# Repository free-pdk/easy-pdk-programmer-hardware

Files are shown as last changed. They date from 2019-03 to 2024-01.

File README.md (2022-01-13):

# easy-pdk-programmer-hardware
Easy PDK programmer for PADAUK microcontroller. EDA, schematic, gerber, bom, housing stl, firmware

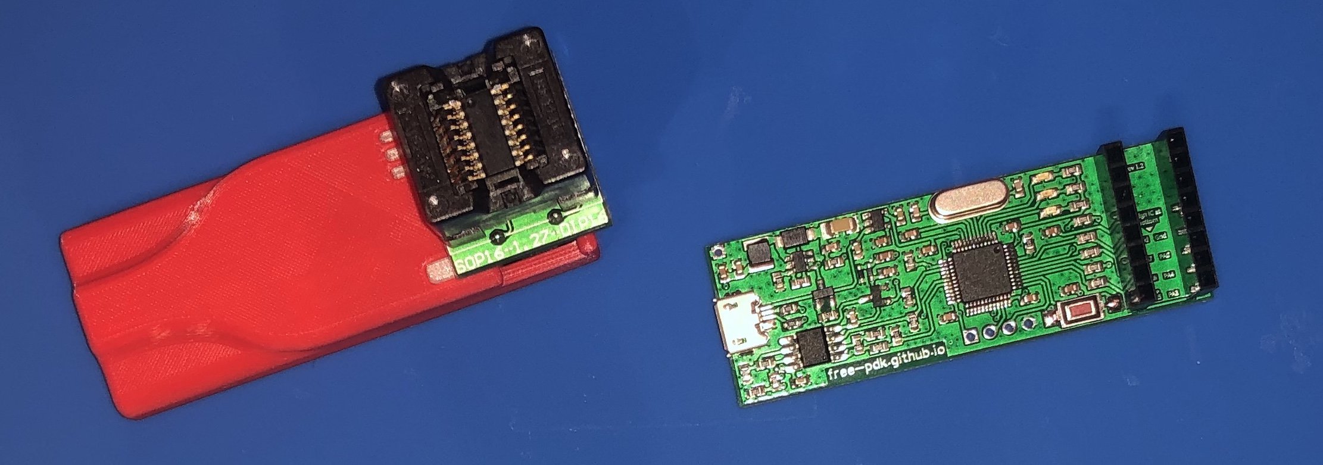
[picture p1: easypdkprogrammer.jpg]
Easy PDK Programmer


Software sources can be found here:  
https://github.com/free-pdk/easy-pdk-programmer-software

PCB gerber files:  
[PCB files](pcb "PCB files")

Easy PCB and components ordering via kitspace.org:  
https://kitspace.org/boards/github.com/free-pdk/easy-pdk-programmer-hardware/

PCB, component placement and assembly pictures:

<a href="https://htmlpreview.github.io/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">==&gt; Click here for interactive component placement bom &lt;==</a>

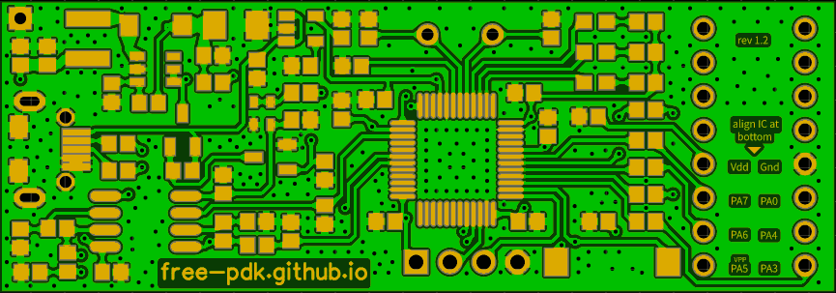
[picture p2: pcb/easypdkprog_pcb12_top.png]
PCB top


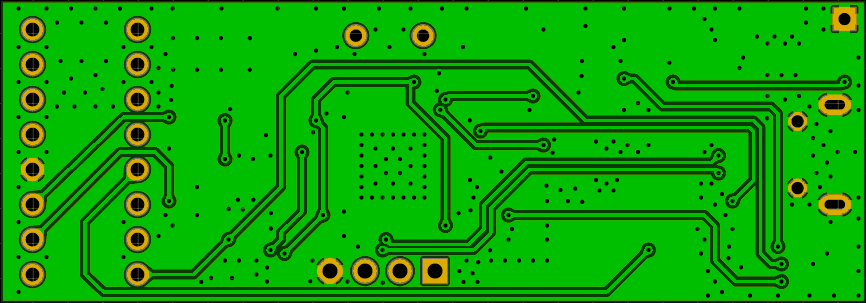
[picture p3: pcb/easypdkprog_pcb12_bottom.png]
PCB bottom


Component placement

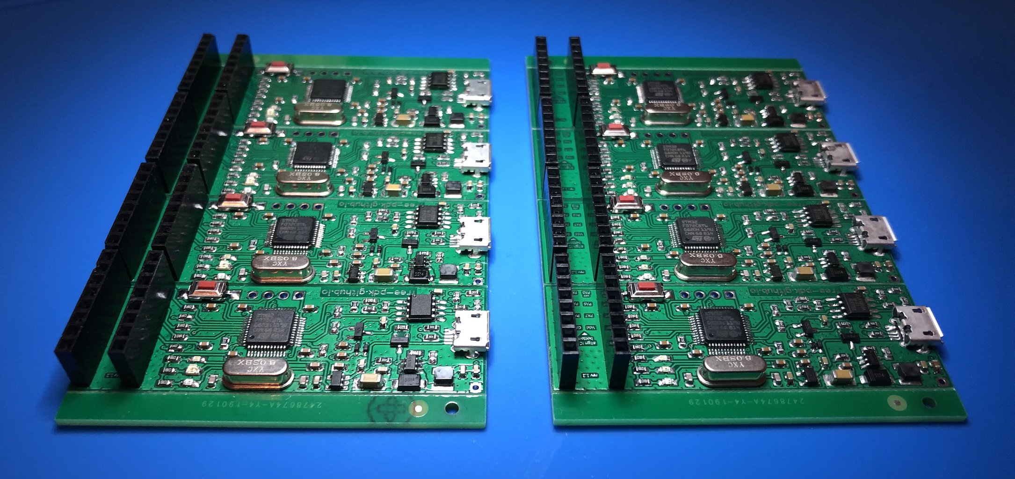
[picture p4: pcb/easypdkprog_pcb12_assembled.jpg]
PCB assembled


After assembling the PCB, you have to install the firmware on the MCU. The firmware can be found in the software repository: https://github.com/free-pdk/easy-pdk-programmer-software/tree/master/Firmware

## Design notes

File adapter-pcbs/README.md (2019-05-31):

# Programming adapter PCBs

This directory contains several adapter pcbs for programming Padauk ICs that
don't have a pinout directly compatible with the easy-pdk-programmer hardware.

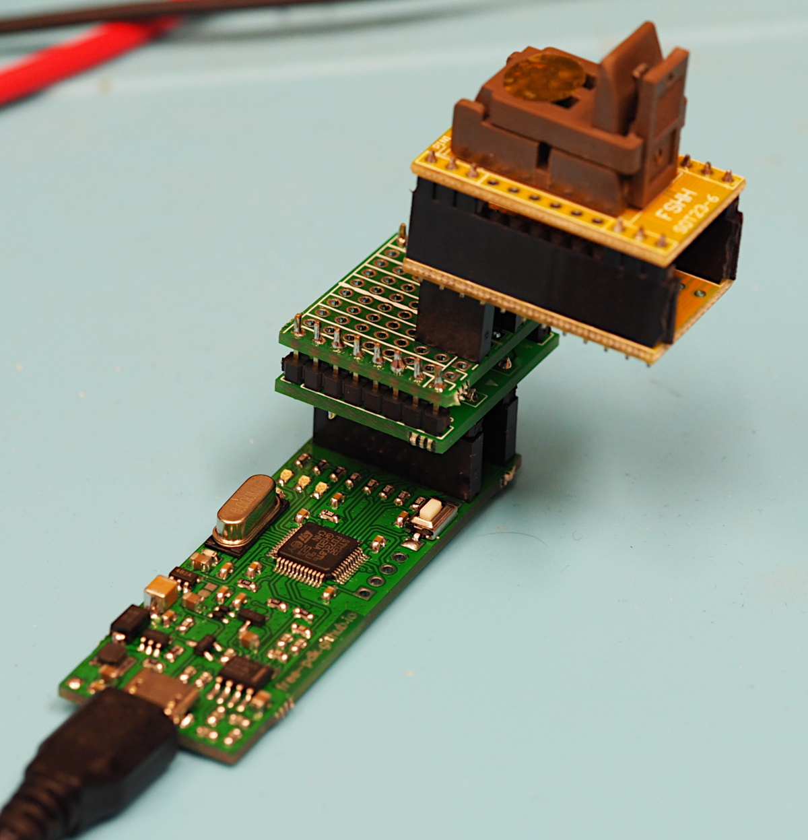
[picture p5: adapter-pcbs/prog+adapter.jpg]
Programmer with adapters


Since most programming sockets available on the market use a pin header spacing
of 0.3" like the programmer itself, one pcb isn't enough for an adapter. So all
adapters are built from 2 pcbs:

  - a bottom pcb, which does the actual routing of the programmer pins to the
    pins needed for the Padauk microcontroller
  - a top pcb, which routes the pins through strait and allows to provide
    socket headers in the necessary spacing for the actual programming socket

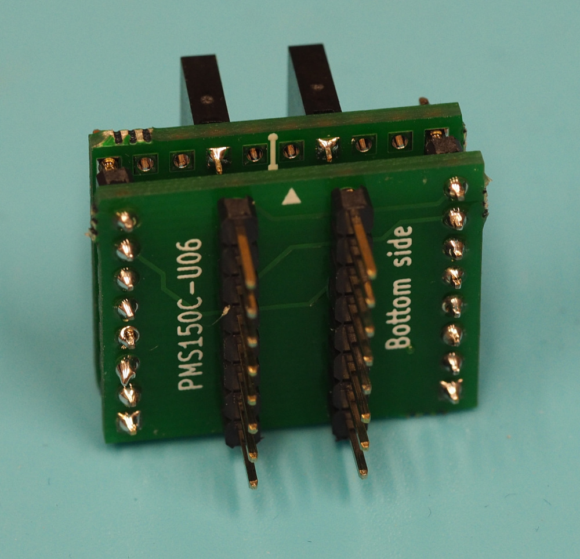
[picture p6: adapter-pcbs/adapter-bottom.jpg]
Bottom pcb of the adapter
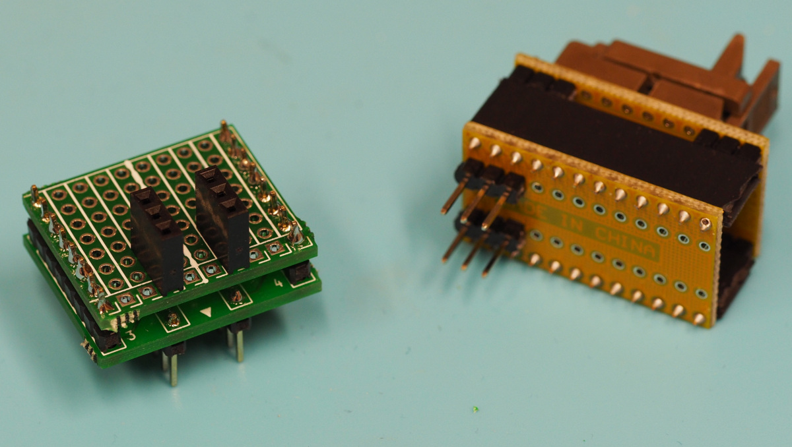
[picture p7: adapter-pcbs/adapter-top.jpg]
Top pcb of the adapter and programming socket
|  |  |

### PMS-Series SOT23-6

This adapter is primarily designed for the PMS150C-U06, but should also work for
other PMS-series ICs in SOT23-6, like the PMS154C-U06 or PMS132B-U06.

### PFS-Series SOT23-6

This adapter is primarily designed for the PFS154-U06, but should also work for
other PFS-series ICs in SOT23-6, like the PFS173-U06.

### SOT23-6 programming socket

The adapter pcbs described above are designed to have a SOT23-6 programming socket plugged into.

I tested this programming socket:
https://www.aliexpress.com/item//32811278237.html
 
### Manual wiring adapter

This is a adapter pcb without connected through tracks between the middle and outer rows.
The white lines in the silkscreen show the breaks. You can solder wires to the holes to
create an adapter for pinouts which don't have their own pcb adapter yet.

### Gerber set

The gerber directory contains a zipped set of Gerber files for a small panel with
all mentioned adapters and the programmer itself.

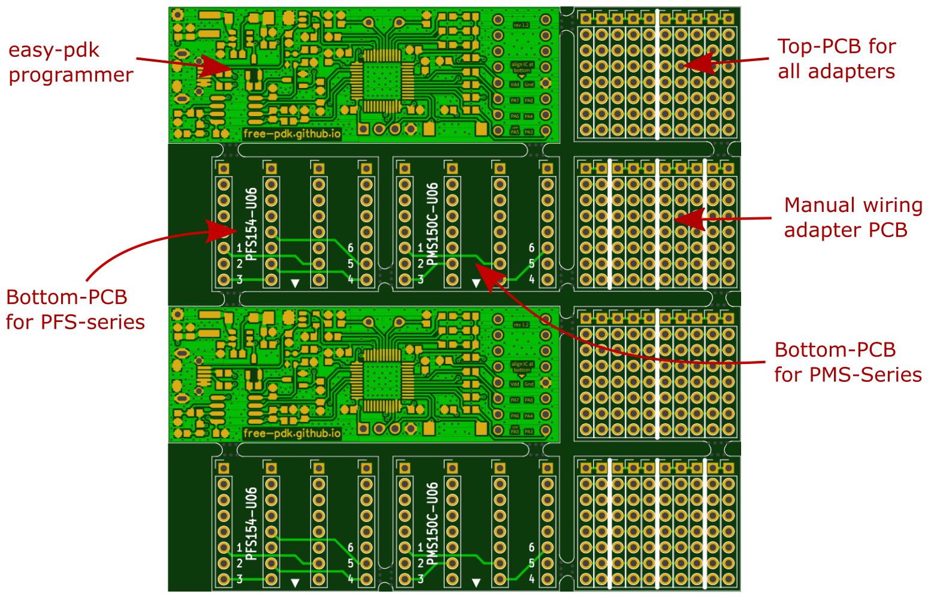
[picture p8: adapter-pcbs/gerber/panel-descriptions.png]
Adapter panel


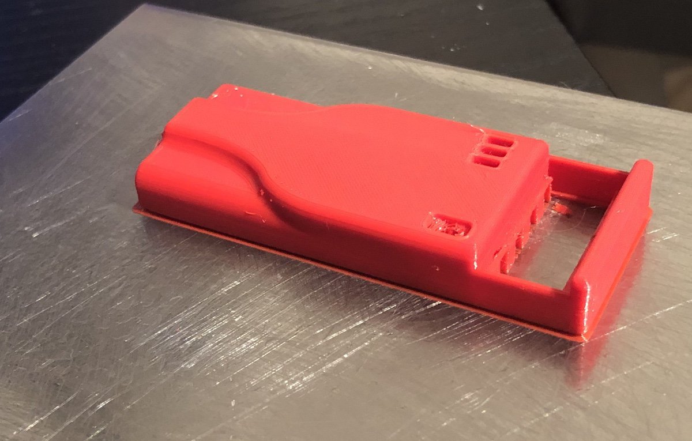
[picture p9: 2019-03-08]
housing/image_housing_top_complete.jpg

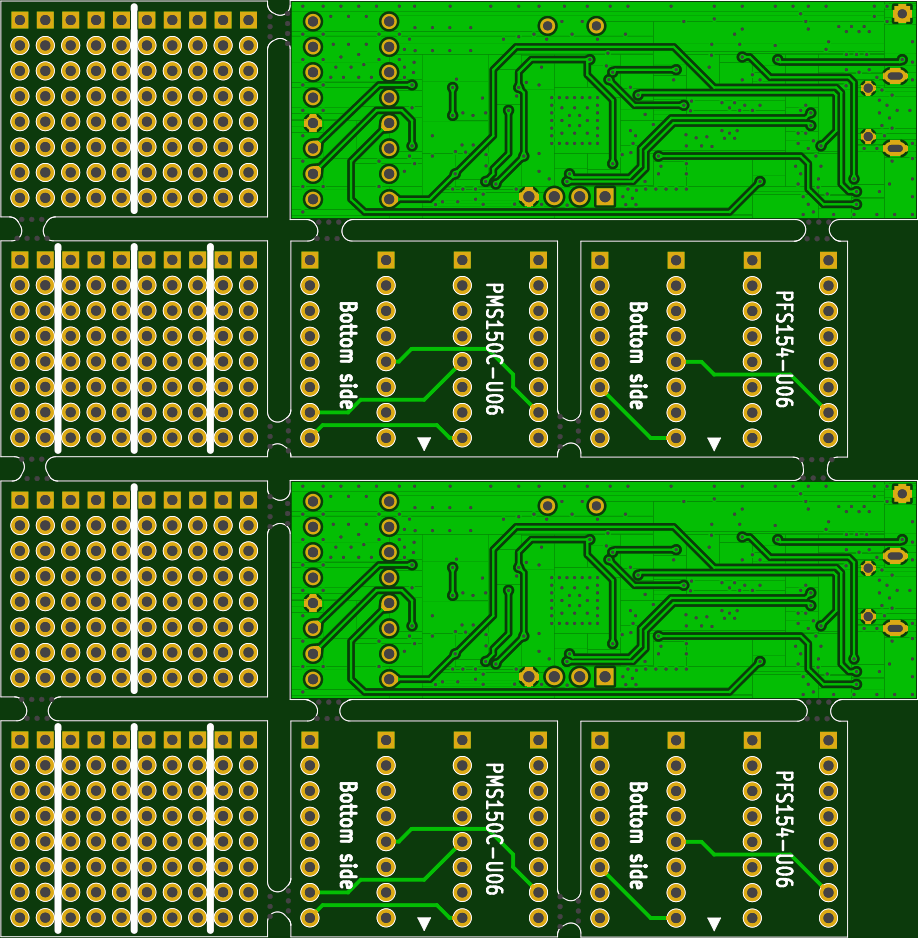
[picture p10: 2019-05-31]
adapter-pcbs/gerber/render-bottom.png

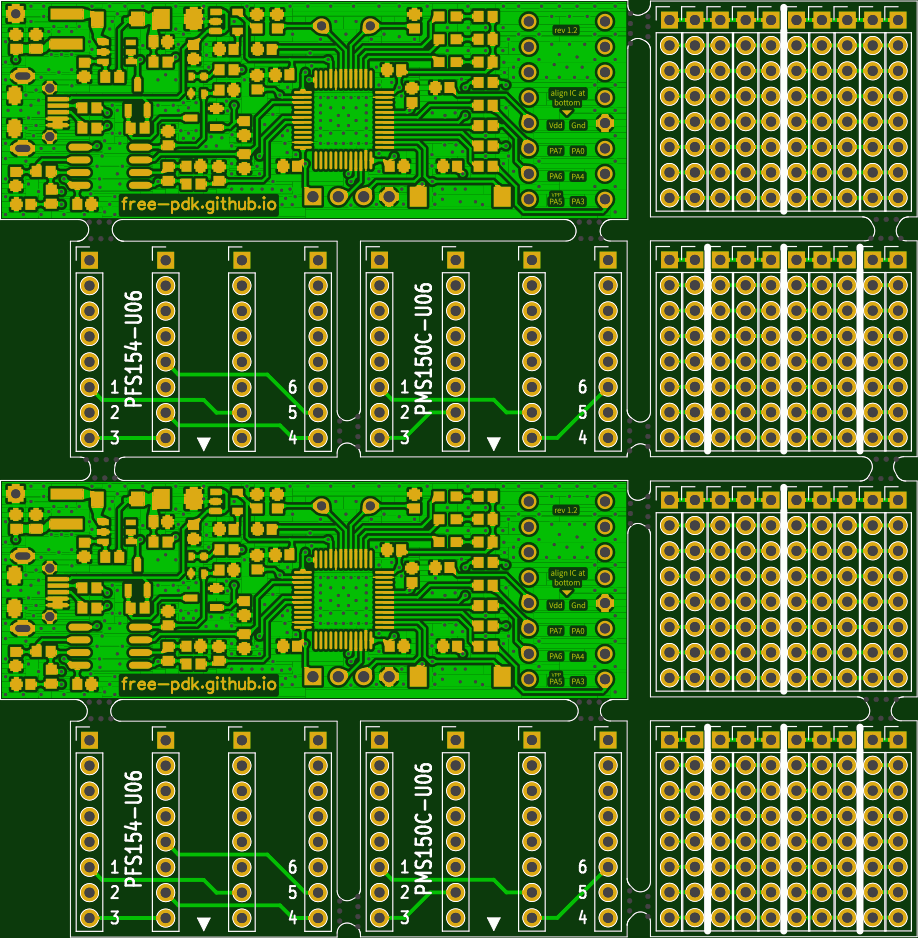
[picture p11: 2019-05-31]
adapter-pcbs/gerber/render-top.png

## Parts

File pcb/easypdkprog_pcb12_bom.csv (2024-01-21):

ID | Name | Designator | Footprint | Quantity | Manufacturer Part | Manufacturer | Supplier | Supplier Part
1 | 47uF | C4 | 1206 | 1 | 1206X476M160NT | FH | LCSC | C172351
2 | IC IN OUT | H1,H2 | 210S-1X8P | 2 | 210S-1*8P L=11.6MMGold-plated black | Ckmtw | LCSC | C27438
3 | STM32F072C8T6 | U1 | LQFP-48_7X7X05P | 1 | STM32F072C8T6 | STMicroelectronics | LCSC | C80488
4 | RT9193-33GB | U2 | SOT-23-5 | 1 | RT9193-33GB | RICHTEK | LCSC | C15651
5 | 4.7uF | C6,C7,C11,C13,C21 | 0603' | 5 | 0603X475K160NT | FH | LCSC | C99229
6 | 20Ω | R10,R11,R24 | 0603' | 3 | RS-03K20R0FT | FH | LCSC | C136605
7 | SWD | SWD | DIP-1X4P-2.54MM-M | 1 | 210S-1*4P L=11.6MMGold-plated black | Ckmtw | LCSC | C124378
8 | 6.8uH | L3 | 3015 | 1 | HPC3015TF-6R8M | TAITEC | LCSC | C155142
9 | FC-DA1608HRK-620D | LED1,LED2,LED3 | LED-0603 | 3 | FC-DA1608HRK-620D | NATIONSTAR | LCSC | C84263
10 | micro USBFemale | USB | MICRO-USB-1 | 1 | micro USBFemale | ValuePro | LCSC | C10418
11 | 100nF | C1,C19,C22,C5,C8,C9,C12,C3,C14,C17,C2,C10 | 0603' | 12 | 0603F104M500NT | FH | LCSC | C42998
12 | 1KΩ | R25,R2,R23 | 0603' | 3 | RC0603FR-071KL | YAGEO | LCSC | C22548
13 | 10K | R1 | 0603' | 1 | RC0603JR-0710KL | YAGEO | LCSC | C99198
14 | 20KΩ | R6,R14,R16,R3,R13,R12 | 0603' | 6 | RS-03K203JT | FH | LCSC | C118368
15 | 240K | R5,R4,R9,R26 | 0603' | 4 | AC0603FR-07240KL | YAGEO | LCSC | C144679
16 | 100K | R17,R15 | 0603' | 2 | RC0603FR-07100KL | YAGEO | LCSC | C14675
17 | 100Ω | R18,R19,R21,R20,R22 | 0603' | 5 | AC0603FR-07100RL | YAGEO | LCSC | C125923
18 | 6.2KΩ | R8,R7 | 0603' | 2 | RC0603JR-076K2L | YAGEO | LCSC | C137614
19 | 8MHz | X1 | HC-49S | 1 | X49SD8MSB2SC | YXC | LCSC | C114147
20 | 20pF | C15,C16 | 0603' | 2 | 0603CG200J500NT | FH | LCSC | C91702
21 | 1TS002E-2700-2500 | SW1 | KEY-TACT-SMD-6.1*3.7*2.5 | 1 | 1TS002E-2700-2500 | HYP | LCSC | C319367
22 | SS14F | D1 | SMAF | 1 | SS14F | SK | LCSC | C110213
23 | GND | P1 | HDR-1X1/2.54 | 1 | Header-Male-2.54_1x1 | ReliaPro | LCSC | C81276
24 | MT3608 | U6 | SOT-23-6 | 1 | MT3608 | AEROSEMI | LCSC | C84817
25 | RB521S-30 | D2,D3 | SOD-523F | 2 | RB521S-30 | SK | LCSC | C122862
26 | BSS84 | Q2 | SOT-23(SOT-23-3) | 1 | BSS84 | SK | LCSC | C112238
27 | BSS138 | Q1 | SOT-23(SOT-23-3) | 1 | BSS138 | SK | LCSC | C112239
28 | AS358AMTR-E1 | U3 | SOIC-8_150MIL | 1 | AS358AMTR-E1 | Diodes Incorporated | LCSC | C141322

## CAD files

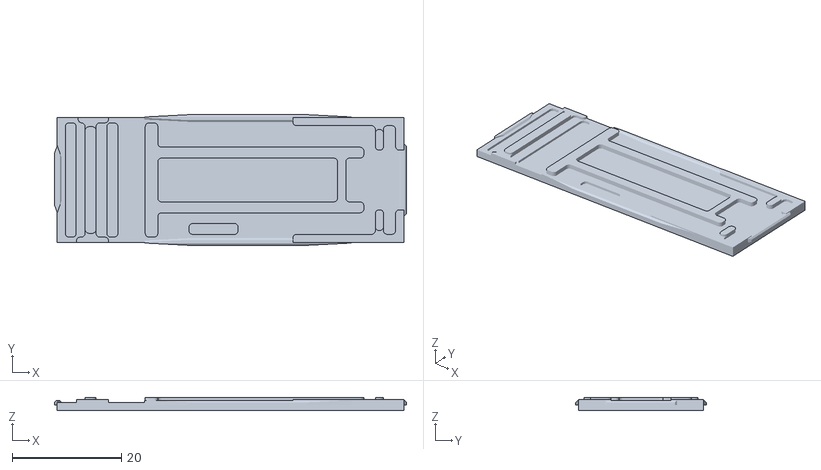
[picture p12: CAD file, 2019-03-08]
housing/easypdkprog_housing_bottom.stl
64.4 x 23.9 x 2.40

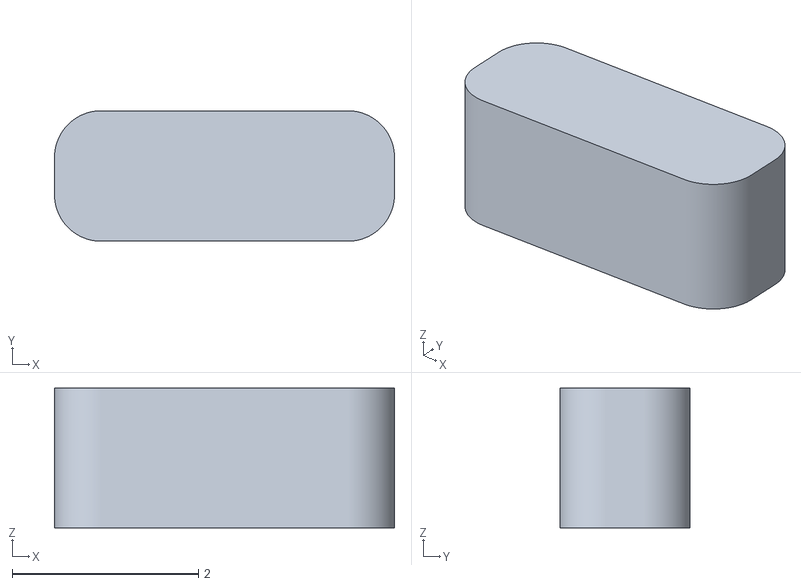
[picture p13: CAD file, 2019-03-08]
housing/easypdkprog_housing_lightguide.stl
3.65 x 1.40 x 1.50

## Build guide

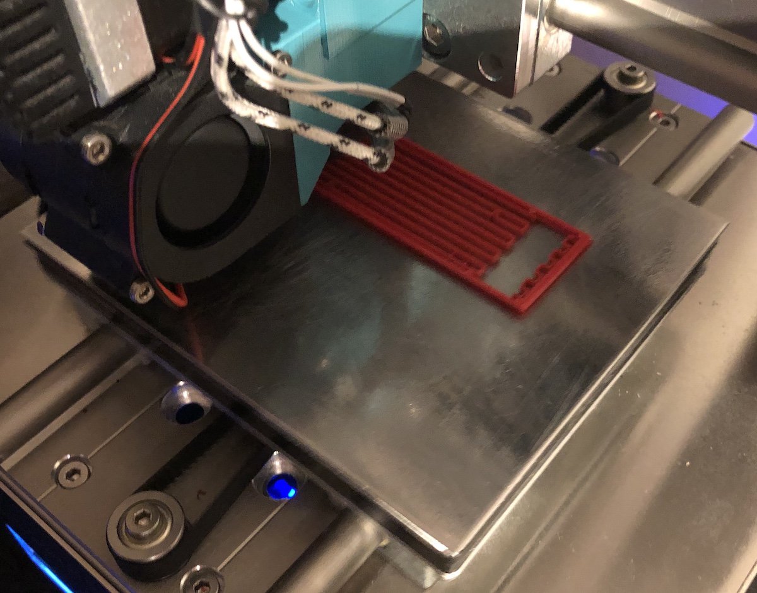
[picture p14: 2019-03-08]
housing/image_printing_housing_top_with_support.jpg

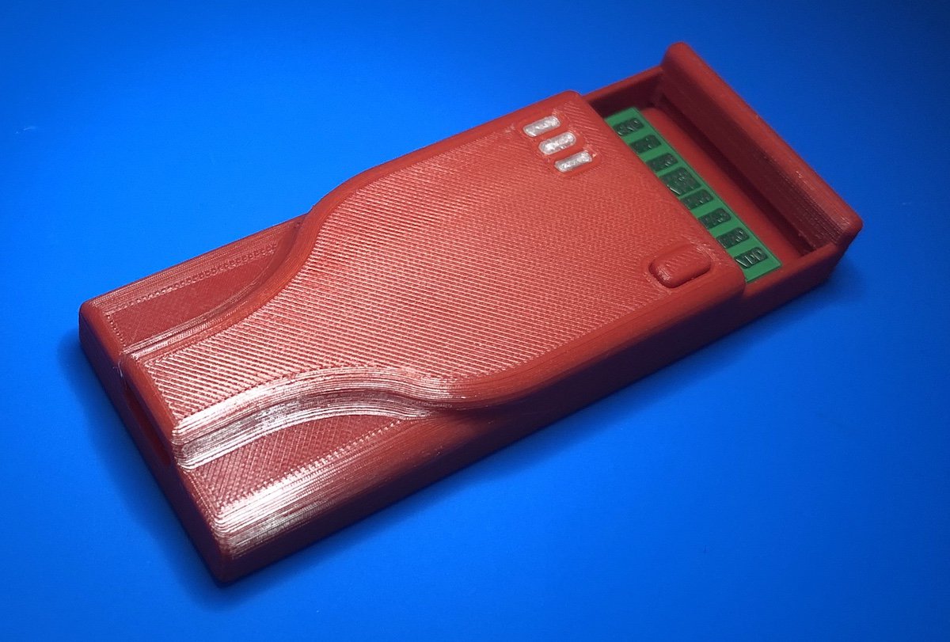
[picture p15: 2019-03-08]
housing/image_housing_assembled.jpg

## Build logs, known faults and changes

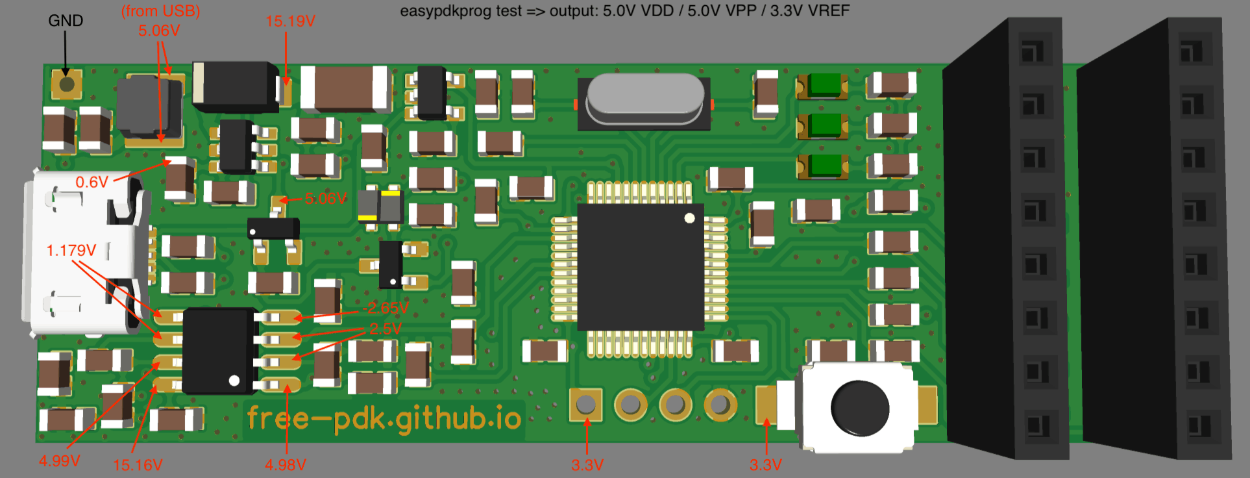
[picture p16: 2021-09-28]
pcb/easypdkprog_pcb12_troubleshooting.png

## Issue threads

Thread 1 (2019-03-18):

Male headers in BOM

electroniceel, 2019-03-18:
The easypdkprog_pcb12_bom.csv has the headers H1 and H2.

The LCSC part listed is C124381. This seems to be a male header.

But all the photos of the pcb show a female header. And I'd also say it makes more sense to use a female header to plug adapters in.

A female header at LCSC would be for example C27438.

freepdk, 2019-03-22:
You are right, they should be **FEMALE** headers.

Something I missed changing when moving to revision 1.2

freepdk, 2019-03-23:
Fixed BOM and easy eda file

Closed 2019-03-23.

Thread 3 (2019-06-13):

Modify the EASYEDA question

themindfactory, 2019-06-13:
I want to modify the SCH and PCB, online I load the SCH and PCB but when you change the SCH it does not change the PCB how do you sync them?? Thanks!

freepdk, 2019-06-18:
This is an EASYEDA specific question. They have a dedicated user forum for this kinf od questions.

As far as I remember: Inside of EASYEDA there is a "Update PCB" button in PCB view. For this to work both SCH and PCB must be in same project.

themindfactory, 2019-06-18:
Thanks, never thought of "other" forum... duh.... nice programmer for Padauk! thanks!

Closed 2019-06-18.

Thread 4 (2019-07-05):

Suggestion: Pin 1 indication on silkscreen

jacobjennings, 2019-07-05:
For components which might be in the wrong orientation, a dot for pin 1 near the correct corner would be helpful. Same for diode direction

freepdk, 2019-07-05:
Hi,

In PCB folder is a file "easypdkprog_pcb12_component_placement.pdf" which has the dots like you asking for.

On such small boards it is not feasible to include silk screen, but with the document from above it is relatively easy to assemble.

Closed 2019-08-15.

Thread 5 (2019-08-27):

[Question] Support for PMC232 PMC234 PGC433 PGC434?

DanielMazurkiewicz, 2019-08-27:
Do you plan by any chance do add support in programmer for these microcontrollers?

PMC232
PMC234
PGC433
PGC434

spth, 2019-08-29:
The PMC232,  was officially released 3 days ago (I don't know about actual availability). The PGC433 and PGC434 are still considered "under development". The PMC234 datasheet was released 4 days ago.
While support for these will be very useful, I guess it will take some time.

freepdk, 2019-08-30:
Support can be added only, if a real physical device is available. It is not possible to add support for data sheet only CPUs.

I do have PMC232 and PMC234. Do you have a project and want to use them? If so I will put them on top of the priority list for device support.

DanielMazurkiewicz, 2019-09-01:
>  If so I will put them on top of the priority list for device support.

@freepdk Thank you, that is a very kind of you, but no rush with that. Would like to at some point drive brushed DC motors and having these industrial grade microcontrollers (PFC and PMC series) supported will probably be a must for such a projects. And after couple of days of research among different brands my priority wish list (based on price and capabilities I will need) would look more like that:

1. PMC156 - SOP16
2. PMC150 - SOP8
3. PMC251 - SOP14

Analyzed that in some cases it will be easier to program and cheaper to have two or even three of above plus some external comparator (if necessary) than having one uC that provide all functions on board.

freepdk, 2019-09-02:
@DanielMazurkiewicz

PMx150C is well supported already
PMx156 I can add next
PMC251 is partially supported already (probe/read works, write I need to finish)

DanielMazurkiewicz, 2019-09-02:
Used that file:
https://github.com/free-pdk/easy-pdk-programmer-software/blob/master/fpdkicdata.c
as reference for table below:

| Microcontroller        | Programmer support | SDCC support |
|:----------------------:|:------------------:|:------------:|
|      PFS154            |         ✓          |              |
|      PFS172            |                    |              |
|      PFS173            |         ✓          |              |
|      PMS130            |                    |              |
|      PMS131            |                    |              |
|      PMS132B           |                    |              |
|      PMS133            |                    |              |
|      PMS134            |                    |              |
|      PMS150            |                    |              |
|      PMS150C           |         ✓          |              |
|      PMS150G           |                    |              |
|      PMS152            |                    |              |
|      PMS153            |                    |              |
|      PMS154B           |         ✓          |              |
|      PMS154C           |         ✓          |              |
|      PMS156            |                    |              |
|      PMS171B           |                    |              |
|      PMS232            |                    |              |
|      PMS234            |                    |              |
|      PMS271            |                    |              |
|      PFC151            |                    |              |
|      PFC154            |                    |              |
|      PFC232            |                    |              |
|      PFC433            |                    |              |
|      PFC434            |                    |              |
|      PMC131            |                    |              |
|      PMC150            |         ✓          |              |
|      PMC153            |                    |              |
|      PMC156            |                    |              |
|      PMC232            |                    |              |
|      PMC234            |                    |              |
|      PMC251            |     partial        |              |
|      PMC271            |                    |              |

Feel free to do whatever you want with that table (would be nice to have it somewhere in readme). Here is a markdown for it:
```
| Microcontroller        | Programmer support | SDCC support |
|:----------------------:|:------------------:|:------------:|
|      PFS154            |         ✓          |              |
|      PFS172            |                    |              |
|      PFS173            |         ✓          |              |
|      PMS130            |                    |              |
|      PMS131            |                    |              |
|      PMS132B           |                    |              |
|      PMS133            |                    |              |
|      PMS134            |                    |              |
|      PMS150            |                    |              |
|      PMS150C           |         ✓          |              |
|      PMS150G           |                    |              |
|      PMS152            |                    |              |
|      PMS153            |                    |              |
|      PMS154B           |         ✓          |              |
|      PMS154C           |         ✓          |              |
|      PMS156            |                    |              |
|      PMS171B           |                    |              |
|      PMS232            |                    |              |
|      PMS234            |                    |              |
|      PMS271            |                    |              |
|      PFC151            |                    |              |
|      PFC154            |                    |              |
|      PFC232            |                    |              |
|      PFC433            |                    |              |
|      PFC434            |                    |              |
|      PMC131            |                    |              |
|      PMC150            |         ✓          |              |
|      PMC153            |                    |              |
|      PMC156            |                    |              |
|      PMC232            |                    |              |
|      PMC234            |                    |              |
|      PMC251            |     partial        |              |
|      PMC271            |                    |              |

```

freepdk, 2019-09-02:
Hi,

in development branch are far more supported ICs (most of them Probe/Read only for now).

"easypdkprog list" shows all supported ICs:

$ ./easypdkprog list
Supported ICs:
 PMC251   (0x058): OTP  : 1024 (16 bit), RAM:  96 bytes
 PMS132   (0x109): OTP  : 2048 (14 bit), RAM: 128 bytes
 PMS132B  (0x109): OTP  : 2048 (14 bit), RAM: 128 bytes
 PMS150C  (0xA16): OTP  : 1024 (13 bit), RAM:  64 bytes
 PMS152   (0xA27): OTP  : 1280 (14 bit), RAM:  80 bytes
 PMS271   (0xA58): OTP  : 1024 (16 bit), RAM:  64 bytes
 PFS154   (0xAA1): FLASH: 2048 (14 bit), RAM: 128 bytes
 PMS133   (0xC19): OTP  : 4096 (15 bit), RAM: 256 bytes
 PMS134   (0xC19): OTP  : 4096 (15 bit), RAM: 256 bytes
 PMS131   (0xC83): OTP  : 1536 (14 bit), RAM:  88 bytes
 PMS171B  (0xD36): OTP  : 1536 (14 bit), RAM:  96 bytes
 PMS154B  (0xE06): OTP  : 2048 (14 bit), RAM: 128 bytes
 PMS154C  (0xE06): OTP  : 2048 (14 bit), RAM: 128 bytes
 PFS173   (0xEA2): FLASH: 3072 (15 bit), RAM: 256 bytes

As soon as Write support is added and tested I want to merge this to master version and make a real release.

spth, 2019-09-03:
SDCC, while not including headers yet, can compile programs for them all, except the PMC251 and PMS271.

Philipp

DanielMazurkiewicz, 2019-09-03:
> "easypdkprog list" shows all supported ICs
@freepdk it requires installing easypdkprog to get to know what is supported and what not, so I still think it would be nice to have it in a documentation

freepdk, 2020-07-17:
The website https://free-pdk.github.io/ is now having a list of truly supported ICs.

Closed 2020-07-17.

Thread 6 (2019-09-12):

Help Resolving Occasional Board Issue (“wrong icid”)

paulreimer, 2019-09-12:
After assembling several boards (over 50% working perfectly!) I have an issue with the other 40%, and I haven’t been able to fix it (by metering signals, reworking some parts, etc).

Specifically, while the USB->STM32 works and the programmer is detected, I get “wrong icid” when trying to flash a PFS173.

Can you suggest what parts/traces to check that might cause this? (shorts, unconnected pins, diodes in the wrong orientation, etc)? It would be great to get those boards working and/or understand the likely causes for future builds.

freepdk, 2019-09-15:
Have you tried the latest version of the programmer software on github (easypdkprog v1.1)?

I changed the voltages in "fpdkicdata.c" for PFS173 a bit (especially WRITE CMD voltage) which improves the situation a bit.

-

To debug the hardware there is an extra program called "easypdkprogtest".

Compile it with "make easypdkprogtest" and the execute it (with no IC attached).

It outputs 5V on VPP and VDD and uses internal ADC to measure it.

When you execute it write down the measurements reported from easypdkprogtest and also measure VDD and VPP with a multimeter.

Expectation: All values should be very close to 5V.
If not you should check that after the 2 diodes you get -2.4V when easypdkprogtest is running (check schematics and measure with multimeter). This is the negative reference for the opamp. In case the diodes are wrong / damaged / not soldered properly you get a wrong negative reference voltage which would explain wrong / shifted output voltages for VDD / VCC which could cause the problem you describe.

paulreimer, 2019-09-15:
Thanks for your help with debugging this! Super helpful to have the `easypdkprogtest` and happily I do have several boards that are working well to compare against.

- I updated all my boards to 1.1 F/W, the working boards still work and the "wrong ICID" boards still report the same.
- I ran `easypdkprogtest` and the working boards have ~5V for both VDD and VPP. The bad boards have ~13.66V for VDD and ~5V for VPP (multimeter confirms this at the IC pins).
- I checked the voltage w.r.t. GND for diodes D2 + D3, and they appear to be similar for both the good boards and the bad boards (-2.7v D3<->GND, and 0.0v D2<->GND, -1.5v<->GND for both diodes on the shared side). I'm not sure where to probe to find 2.4v.

So now I'm wondering about the opamp (maybe that needs to be replaced?), and also about the xtal as you suggest (but continuity test seems good.) If you have any other pointers, please let me know! I'm already feeling a lot better knowing that I can confirm some of the symptoms with `easypdkprogtest`.

freepdk, 2019-09-16:
Hi,
>     * I ran `easypdkprogtest` and the working boards have ~5V for both VDD and VPP. The bad boards have ~13.66V for VDD and ~5V for VPP (multimeter confirms this at the IC pins).
This explains everything.

Just to be sure. You measure +13V on VDD and +5V on VPP ? This scenario is almost impossible and could be caused by wrong resistor values on the DAC lines only.

>     * I checked the voltage w.r.t. GND for diodes D2 + D3, and they appear to be similar for both the good boards and the bad boards (-2.7v D3<->GND, and 0.0v D2<->GND, -1.5v<->GND for both diodes on the shared side). I'm not sure where to probe to find 2.4v.
I said -2.4V, you measured -2.7V which is ok as negative reference for the opamp (anything less than -2V is fine).

> So now I'm wondering about the opamp (maybe that needs to be replaced?), and also about the xtal as you suggest (but continuity test seems good.)
The XTAL + decoupling caps just need visual inspection of soldering. If you say they are good then they are good. (The 13V problem has nothing to do with XTAL).

* check that there are no solder blobs on MCU pins shorting the DAC outputs to 3V (MCU pin 14, pin 15)
* check resistor values on the dac outputs: **R4**, **R6**, R8, R9 (most likely something wrong with one of these)

freepdk, 2019-09-22:
@paulreimer
Could you solve your problem?

paulreimer, 2019-09-22:
Thanks for checking @freepdk!

I checked the resistor values and they all seem to be correct, the value varies somewhat maybe due to low-ish tolerance, but it doesn’t seem like any values were swapped or shorted. I’m not sure what else to check, but I might order extra parts from LCSC and try to replace the STM32 or op-amp and see if that helps?

Feel free to close this issue if there’s nothing else to check (maybe I cooked the boards a bit too much). I can post something if I learn more about this issue.

freepdk, 2019-09-22:
@paulreimer
Better to find the cause so others can participate from it. I have something like a "troubleshooting" document in mind.

Here a first start:

```
Reference voltages when running easypdkprogtest:

                   +-------+
                   |   O   |
(DAC-VPP) 1.18V -> |5  P  4| <- -2.7V
          1.18V -> |6  A  3| <-  2.49V (DAC-VDD)
(VPP)      5.0V <- |7  M  2| <-  2.49V
          14.9V -> |8  P  1| ->  5.0V  (VDD)
                   |      .|
                   +-------+
```

Please measure the voltages on your non working boards and report back.

Closed 2020-07-17.

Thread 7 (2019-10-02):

VPP/VDD voltage capped to 3.45V

cirlam, 2019-10-02:
Hi,

Firstly, thank you for all the hardwork developing this programmer!

I have a similar (ish) problem to [https://github.com/free-pdk/easy-pdk-programmer-hardware/issues/6](https://github.com/free-pdk/easy-pdk-programmer-hardware/issues/6)  with a hand soldered pcb.

When using easypdkprog probe, It responds with no MCU found (PFS-154C in the socket).

Using easypdkprogtest, it only gets to 3.46v for vdd and 3.44v for vpp. I've confirmed these values with a multimeter. Voltage around the diodes is identical to Paul - (-2.7v D3<->GND, and 0.0v D2<->GND, -1.5v<->GND for both diodes on the shared side).

If I change easypdkprogtest to request 1v or 2v it works perfectly, however it cannot go any higher than this. If I change easypdkprogtest to 100.0, it remains at 3.46v/3.44v.

Visual check of the PCB with microscope looks OK from what I can see.

Any ideas of what I should be checking to resolve this? Thank you!

freepdk, 2019-10-04:
Hi,

this sounds like the dc dc is not generating the 14V. Look at the coil / big diode / the DC DC ic and measure voltages there (when easypdkprogtest is running).

==> check U6  when easypdkprogtest is running:
pin 4/5: input voltage (should be 5V, if is not 5V check the 2 transistors Q1 and Q2)
pin 1: output of high voltage going to big diode (should be around 14V)
pin 3: input of feedback voltage (should be something >5V, sorry can't measure right now)

My guess: big diode is soldered backwards or Q1/Q2 is mixed up.

cirlamOB, 2019-10-04:
Thank you for the help! I will check these this evening and get back to you.

cirlam, 2019-10-04:
Thank you for the help!

I will check these this evening and get back to you.

cirlam, 2019-10-05:
Success! I mistakenly soldered a 100k resistor to R1. Now works fine and detects IC's ok.

freepdk, 2019-10-05:
Great to hear.

Wrong R1 / R5 values will cause a wrong feedback to the DC DC so the output voltage will be incorrect.

Thanks for the feedback.

Closed 2019-10-05.

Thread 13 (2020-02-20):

Documentation: User Manual

Zitt, 2020-02-20:
Is there a user manual somewhere?
Specifically; I'm looking for the definition of the three LEDs tied to PC12-15.
What purpose does each serve?

freepdk, 2020-02-26:
Hi,

Right now the 3 LEDs are used for the following purposes:

LED3 : active during probing/reading/writing/running (outer most LED)
LED2: active when UART sends data to IC (when running a program)
LED1 : active when UART receives data from IC (when running a program on IC and IC sends data)

In firmware source code in file "fpdkusb.c" you can see the definition:

```
static const uint32_t FPDK_LED_UART_RX = 1;                                
static const uint32_t FPDK_LED_UART_TX = 2;                                
static const uint32_t FPDK_LED_IC      = 3;
```

This means LED1+2 will only light up when you use the UART (see UART demo programs).

Zitt, 2020-04-11:
Closing.

Closed 2020-04-11.

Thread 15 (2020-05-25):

Should the design be easy to get via JLCPCB (and distribution in the EU be feasible)?

spth, 2020-05-25:
AFAIK, the design uses a lot of components from LCSC. LCSC cooperates with JLCPCB for board making and assembly.
While JLCPCB is willing to add some LCSC parts on request, however JLCPCB explicitly does not support connectors (they say connectors interfere with their approach of doing assembly before depanelization).

This makes the following option attractive:

* Have the connectors as through-hole components to make them relatively easy to hand-solder.
* Make the rest of the design orderable at JLCPCB

This has the added advantage of making it possible to sell the device as a kit in Europe: In the EU, it is practically illegal for private individuals and small companies to make electronic devices to sell or give away fro free (WEEE Directive). However, AFAIK, it is still legal to sell kits that require substantial assembly, such as soldering.

At first sight, it seems the only change required would be to use a through-hole USB connector.

cpldcpu, 2020-05-25:
I like the idea of the trough hole usb connector. Jlcpb is not able to
mount any usb connector so some solution is needed anyways. It would be a
huge usb-a Plug though. No usb-c socket available in that

On Mon 25. May 2020 at 08:16, Philipp Klaus Krause <notifications@github.com>
wrote:

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

cpldcpu, 2020-05-25:
Another component that is bizarrely missing from jlcpcbs catalogue is a proper power inductor, btw.

spth, 2020-05-25:
I have been in contact with JLCPCB, and they are willing to add LCSC surface-mount parts on request to their catalogue (long term goal is to have them all anyway), with the exception of connectors.

cpldcpu, 2020-05-25:
Yes, but most components will stay as "extended", which means there is an additional set up fee. It makes a lot of sense to redesign to only use "basic" components. So far that works, the only extended component is the MCU.

spth, 2020-05-25:
I guess a set up fee is not a big deal as long as it doesn't affect too many components. Do you know how much the setup fee per part is.

cpldcpu, 2020-05-25:
It's $3.00. Does not sound much, but consider that they will assemble a maximum of 5 boards. So each board will be $0.60 more expensive for every non-basic part that is used.

cpldcpu, 2020-05-25:
But it's not an issue, since the "lite" design (see EEV forum) is only based on "basic" components.

spth, 2020-05-25:
> It's $3.00. Does not sound much, but consider that they will assemble a maximum of 5 boards. So each board will be $0.60 more expensive for every non-basic part that is used.

I just checked their website. It seems the limit has been raised to 50 boards. And for those wanting to go over the limit, they recommend panelizing the design (I guess they would then assemble 50 panels). Seems enough for now.

cpldcpu, 2020-05-25:
Well, I frequently use their service and two weeks ago it was still limited to 5.
Panelizing is something that would help, but easyeda does not support panelizing of the component placement. It's rather weird really. A workaround would be going to the KiCAD design.

vanmierlo, 2020-05-29:
When the connectors are left out, there is exactly one through-hole component left: the crystal. Would it not be prudent to replace that by an SMD variant then?

cpldcpu, 2020-05-31:
There are also the header for the programming, which is through hole.

The crystal is optional anyways, since the MCU is able to synchronize from USB.

freepdk, 2020-06-01:
@cpldcpu

In case this needs to be identified as a board variant (which I think might not be required) it would be a good idea to connect one of the unused STM32 pins (e.g. choose one from PB8-PB15) to GND.
This would make it possible to identify this hardware variant in the firmware and to handle things different in case it's needed.

cpldcpu, 2020-06-01:
>In case this needs to be identified as a board variant

I conntected PB8 to GND in the design. I posted a changelog in the EEVblog thread.

kasbah, 2020-10-30:
I'd be interested to help organise a group-buy of a JLC assembled PCB through [kitspace.org](https://kitspace.org). We have just begun testing the waters of a group-buying functionality (https://github.com/kitspace/kitspace-v2/pull/13).

We deployed a basic shop, which, for now, is just has a straight-forward ["buy it now" of components for my friend's workshop](https://shop.kitspace.org/buy/electron-detector-parts-only/). But we are able to take payment, take care of shipping everything out internationally, etc.

If we can gather all the required info together, agree on how any profit needs to be shared, etc. I can set up a page where people can register interest and pay and organise the manufacture and shipping out (or issue full refunds if MOQs are not met).

kasbah, 2020-11-01:
Hi @cpldcpu, great, I didn't realise you were the same person as tim_ on EEVblog. I'll email you.

The idea is that Kitspace could take care of everything that needs to be done to get the assembled boards into the hands of the people that want them. So that includes ordering, shipping, customs, handling refunds etc. Of course we want to make sure people that did the design work get a fair share of the money too.

Regarding the MCU stock, I've actually been coding up a stock-alert web app for JLC that emails you when your desired quantity is back in stock. Let's see if I can get that finished so it can help with this.

cpldcpu, 2020-11-01:
hi @kasbah, indeed, waiting for your mail then.

Regarding sharing of any leftover money, I guess we'd need to figure out something that helps the community. I certainly would not like to take any direct renumeration. The programmer was developed by @freepdk, I just made some tweaks to it to make the design more compatible to JLCPCB and did the test runs and evaluation.

Priority should be to make the programmer more accessible, as this has been a difficulty for many.

I don't know whether anybody else has opinions this?

cpldcpu, 2020-11-01:
Btw, here is the current state of the lite programmer design log. That's the best source for information I have right now.

[EasyPDKprog_lite.pdf](https://github.com/free-pdk/easy-pdk-programmer-hardware/files/5470996/EasyPDKprog_lite.pdf)

cpldcpu, 2020-11-02:
@kasbah

I elected to publish it to a separate repository instead of an add on to this one, to avoid too much confusion. You can find the lite version here: https://github.com/free-pdk/easy-pdk-programmer-lite-hardware

It's still incomplete. @freepdk can you check whether everything is ok? I noticed you changed the license recently, will update to CC.

cpldcpu, 2020-11-25:
@kasbah

Just checking: is this useful to you in any way? Are there still open questiosn? (Not sure how to translate the eyes emoji ;) )

kasbah, 2020-11-25:
Hi, yes very useful indeed, thanks. By "eyes" I just meant, at the time: I've seen this and will try it out later, ha.

Later I went through the process of uploading it to JLC assembly, which seemed to work fine.  But as you commented before, crucial components are out of stock at the moment so it wasn't enough to get a cost estimate. (I need to get my stock-alert thingy finished.) I also noticed one component which we could maybe switch out for something that JLC normally carries, will take another look to give you an exact part.

cpldcpu, 2020-11-25:
Ah ok, thanks for feedback. Someone in another forum mentioned that many of the STM microcontrollers are on allocation right now. So that may not be a problem limited to JLCPCB. Hopefully we will see new stock soon.

EDU-BR-TAR, 2021-06-03:
I have a humble idea to lower the cost of the board, I can make a shield for the bluepill board many people have this board in their hands, I just need someone's help to modify the firmware for the stm32f103c8t6

freepdk, 2021-06-03:
> I have a humble idea to lower the cost of the board, I can make a shield for the bluepill board many people have this board in their hands, I just need someone's help to modify the firmware for the stm32f103c8t6

There was a discussion about this already. STM32F10x does not have 2 DACs which are needed in order to provide the reference voltages for the opamp.

**And a big heads up to all people thinking they have a so called "BluePill" board.**
In some other projects I did, it turned out that >90% of all sold bluepill boards come with a FAKE STM32 IC. Some of them (using the GD32F103) seem to be 95% compatible but some using the cheaper fakes (CS32F103/CH32F103) struggle with many problems (even USB is not working without adding quirks to the firmware). The most annoying fact is that the fake ICs  also come with a fake label claiming to be a "real" STM32F103. Dealing with this situation in a hobby open source project is something I can strongly recommend to AVOID.

My point of view:
==> There is no STM32F103 anymore which "many people" have (almost all of them buying clones)
==> Do not use STM32F103 for any project where you do not manufacture the complete hardware yourself and you source the IC directly from ST / DigiKey / Mouser / ...
==> Do not create add on hardware for devices which most likely contain clone STM32F103. You will waste more time dealing with the clone problems than you can spent on the actual project.

EDU-BR-TAR, 2021-06-04:
i understand , thanks for answering

________________________________
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

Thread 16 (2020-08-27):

No easy way to thank you, short of opening an issue

brainsmoke, 2020-08-27:
I ordered and assembled your programmer and it works perfectly!
But not I'm having difficulty to find a method of thanking you, short of opening an issue.

Once this whole pandemic is over I would like to buy you a beverage at some hacker con
if you're into visiting those.

Cheers,
Erik

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

sengiv, 2021-06-08:
how much did this cost you?
where did you source the parts?

looking to build one like yours, but my cost (lcsc.com) seems to high.

brainsmoke, 2021-06-08:
The STM32F072 has been going up in price from US$2.50 to US$6.92 (and it's out-of-stock)
I paid US$23.65 for enough parts for three (with extras for many parts), but the same parts list
is US$33 now excluding the STM32.

This is the BOM for the order for comparison: (I might have left out stuff that I had already)
At the time the boost converter was not in stock, so I used a compatible part.

[LCSC_Exported_20210609_011821.csv](https://github.com/free-pdk/easy-pdk-programmer-hardware/files/6618480/LCSC_Exported_20210609_011821.csv)

sengiv, 2021-06-09:
@brainsmoke thanks for your reply, you're right prices have changed. At the current prices it's becoming more economical to get the original programmer : )

Btw, if you dont mind sharing some details about your project. What are you using this mcu's for? Production or hobby? Would you say these mcu's are worth the extra work?

As far as I can see the extra cost & work doesnt make sense unless I'm going for scaled production.

terryspitz, 2023-06-21:
Update: I managed to order min. quantity 5 of these from JLCPCB for £28, including the USB socket, but excluding the microswitch, crystal and inductor which I got from LCSC and soldered myself.  They work for programming an on-circuit PFS154 SO8, but don't calibrate successfully (I didn't realise I needed to expose PA4 pin).

With other parts, shipping & duty (to post-Brexit UK) I'm willing to sell the extras at cost: £12/$15/€14 plus shipping to your location.

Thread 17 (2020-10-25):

No input protection

Icaltary, 2020-10-25:
First of all, thanks for the great work!

But since I managed to kill my programmer, I noted that there are a few avoidable failure modes that could lead to the destruction of the programmer and / or the target.

The five volt tolerant inputs of the STM32 do not have any protection towards the positive rail, so an accidental short between VPP and an input pin of the programmer will fry that pin.

If for some reason the negative voltage is not being generated, the target vdd could rise up to the 15V, which will kill the target and the programmer.

Damage to the programmer could be easily avoided by adding zener diodes to the inputs (after the protective resistors). About the negative voltage for the OpAmp, it may be better to just use an OpAmp that works down to the negative rail and remove the charge pump.

cpldcpu, 2020-11-01:
These are good points.

Regarding the negative voltage generator: Both this one and the power switch are eliminated in the lite design, therefore this failure mode should be eliminated.

Regarding the zener diodes: I am not sure how exactly you would do this, as it would also be preferrable not to destroy the zener diodes if a pin is connected to 5V?

Icaltary, 2020-11-01:
The STM32 inputs have an absolute maximum voltage of VCC + 4V, so using zeners with a voltage of about 7V (probably a bit less) from the IOs to ground should do the trick. They wouldn't be used for to the VCC / VPP pins, just for the 5 other IOs. Since the 7V is beyond the maximum target VDD (6.6V), it also won't induce any additional load on that. About destroying the zeners, I guess this may be an issue if you are using small diodes and the VPP is injected into that pin for an extended period of time. But usually the programmer should turn off VPP rather quickly in any case, so this should be fine.

cpldcpu, 2020-11-02:
Ok, thank you, understood. I also checked the documentation of the STM32F072 now. The maximum allowable voltage would be 3.3V+4V=7.3V, so the Zener voltage should be very close to 7V, maybe 6.8V to 7.2V.

There are no suitable devices in the basic parts library at JLCPCB, but I will look into adding footprints for a potential lite r2 design, so people can populate it afterwards. Due to the additional capacitive loading, it may also be necessary to adjust some programming voltages.

In addition, there needs to be a software protection layer. Some ideas:

- _Before programming_: Short check between VPP and GPIO by wiggling VPP and checking whether any other pint changes. Of course there could be false positives if the padauk-mcu in the test socket also has a program on it.

- _During programming_: Short check on VPP by monitoring the voltage.

@freepdk what do you think?

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

cpldcpu, 2020-11-02:
@Icaltary

What do you think about this device? https://datasheet.lcsc.com/szlcsc/ON-Semicon-ON-SMF05CT1G_C15879.pdf

It's available as basic part at JLCPCB. One problem is though, that the breakdown voltage is a little low. If it is used after the series resistors this may still be ok, though, since it's not an issue if logic levels are limited.

Icaltary, 2020-11-03:
The SMF05CT1G looks almost perfect since the breakdown voltage is 6.2V - 7.2V. The padauk controllers are specified up to 5.5V only anyway, so the 6.6V of the programmer is more of a theoretical limit that shouldn't be reached during normal usage.

I wouldn't be too worried about capacities. The programmer has already a 100n cap parallel to the VPP and VDD. Adding a few more pF to the IO's shouldn't change anything.

About the software based approach, I'm not sure if that's viable. The IOs may (and probably will) change even if everything is connected correctly. This is especially true for MTP controllers, since they may start executing their program.

freepdk, 2020-11-05:
A simple check for shorts could be added to software. Maybe there is no need for the protection diodes then.

Maybe something like this:

- create 2.5V as VPP
    * check if any of the IO pins sees a "high"  ==> if so, abort with "VPP short detected"
- create 4.5V as VPP and 2.5V as VDD (this enters programing mode and prevents the IC from starting the user program)
    * check if any of the IO pins sees a "high" ==> if so, abort with "VDD short detected"

Icaltary, 2020-11-05:
You are probably right. You would have to turn on the Pull-Downs to prevent leakage current from triggering that detection. And you need to verify, that all IOs are indeed LOW in the programming mode / while only VPP is applied. Btw you don't really need to detect VDD shorts, since (if there are no HW faults) the VDD shouldn't be able to exceed 6.6V anyway.

It wouldn't prevent damage from a faulty target or a short that occurrs during programming, but this may be acceptable.

Another option for the diodes would be to add clamping diodes against the 5V from the USB. This would be very simple, but would limit the max voltage to 5.7V. That's still greater that the 5.5V max, but its pretty low.

cpldcpu, 2020-11-05:
A software check would be preferrable in any case, since it could be easily applied to existing programmers. And indeed, if it's possible to do the check while the device is in a controlled programming mode, it should be quite robust, too.

I will add the footprint of the protection device to the next revision of the lite programmer if I get around, then people could still add it as a precautionary measure.

Clamping vs. the USB supply somehow feels not right.

freepdk, 2020-11-05:
I'm not sure, but maybe sending signals out to the IOs and use the ADC to check if voltage changes on VPP/VDD while virtually creating 0V for VPP/VDD might also be an option.

cpldcpu, 2020-11-06:
Maybe something more pragmatic: How about entering programming mode using voltages below 7V and simply trying to read the device ID? If that works, then most likely there is no short between VPP and one of the lines used for programming. In addition one would need to check whether any of the lines that are not used by the programming interface are toggled.

freepdk, 2020-11-06:
> Maybe something more pragmatic: How about entering programming mode using voltages below 7V and simply trying to read the device ID as a first step? If that works, then most likely there is no short between VPP and one of the lines used for programming. In addition one would need to check whether any of the lines that are not used by the programming interface are toggled.

The **probe** command is doing that (4.5V VPP / 2.5V VDD + READ).

So just adding the probe procedure before READ/WRITE/ERASE should (implicitly) do the thing?

cpldcpu, 2020-11-07:
Indeed, that would be a simple and robust solution that would at least catch some of the most obvious "miswirings".

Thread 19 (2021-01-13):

How should I program the STM32?

datedave, 2021-01-13:
Hi,  I wanna have a go a programming some PMS150C devices, and so need a programmer....

So forgive the dumb question (and not sure the best way to ask..), but how should I programme the STM32 that is on the board?
Is the on board USB used to program the STM32?
what programming software should I use to program the STM32?

thanks

spth, 2021-01-13:
This information can be found in the repository for the software, in particular in thr README for the firmware that goes onto the STM32 (summary: use the on-board USB with dfu-util):
https://github.com/free-pdk/easy-pdk-programmer-software/tree/master/Firmware

Closed 2021-01-30.

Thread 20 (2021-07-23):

Alternate parts?

jamesadevine, 2021-07-23:
Hiya!

Could you recommend an alternate inductor for HPC3015TF-6R8M?

Since it's not my design, I do not have all of the context that went into selecting this inductor. A recommendation that is easily sourcable would be great if possible!

Thank you for the great work 😄

brainsmoke, 2021-08-02:
https://lcsc.com/product-detail/Power-Inductors_Taiyo-Yuden-NR3015T6R8M_C87173.html worked for me

kimstik, 2022-03-25:
I have no issues with IP20124R7MPL9 or CB2012T100MR

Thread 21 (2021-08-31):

SWD pin

Skywalkerf34, 2021-08-31:
Hello,

thanks for sharing  this really cool project
I have do assembly for few of those and trying to understand

What is usage of SWD ?

Do you have any schematic/PCB design available for Eagle PCB

Rgds

freepdk, 2021-09-17:
SWD is a protocol like JTAG. The pins can be used to connect a debug probe like "STLinkV2" during development of the firmware for the programmer.

https://en.wikipedia.org/wiki/JTAG#Similar_interface_standards

Schematics for easyeda ( https://easyeda.com/ ) are in this repository. Eagle is not available

benlovage, 2022-12-15:
What's the pinout on the SWD header? If everything works, connecting the ground pin and using the guess-and-check method should be a viable way to figure out the pin order, but if something's wrong, not knowing the pins would make debugging the circuit a PITA.

freepdk, 2022-12-15:
Hmmm... you are right, 2 SWD pins are not labeld in schematics.

But, SWD has only 4 pins (VCC,GND,SWDIO,SWDCLK).
Pin 1 (square) is shown in schematics as 3.3V and Pin 4 is GND.

So you only would need to try 2 possibilities. Chances that you get it right first time is 50%  :-)

For your reference:

Pin1 (squared): 3.3V
Pin2: SWDIO
Pin3: SWDCLK
Pin4: GND

Closed 2021-09-17.

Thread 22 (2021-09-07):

Nothing found

Skywalkerf34, 2021-09-07:
Hi,

This look very good projet and I wanna have programmer for some cheap board later so
I have done assembly for 5 Programmer using provided GERBER files
I successfully program the ST32 chip
I am under windows 10 and install STM32 driver
Using easypdkprog list or --version I get answer (confirmed version 1.3)
But when I wanna try the probe command the answer is "probing IC... Nothing found" with a PFS154 or PFS173 fresh new chip

This append on all of the programmers, so I guess something wrong :-5
What checking on PCBA can I run to fix this ?
What command can I pass to check all ?

Rgds

freepdk, 2021-09-17:
You should compile and run easypdkprogtest and then check the output voltages reported from easypdkprogtest + measure the voltages on VDD and VPP.

To compile easypdkprogtest on windows, please have a look at the INSTALL file in the software repository:
https://github.com/free-pdk/easy-pdk-programmer-software/blob/master/INSTALL

(you need to install MSYS2 and install a compiler (gcc) for MinGW or MSYS2 : you can find multiple guides on the internet like this one: https://www.devdungeon.com/content/install-gcc-compiler-windows-msys2-cc)

Skywalkerf34, 2021-09-25:
Hi freepdk,

Thanks for all those links, I have installed MSYS2 and all suggested package
Now my question is how to compile with that tool?
I run "MSYS MinGW 64-bit" from Start menu.  and get a shell interface waiting for some instruction
 Now how I can call  gcc to build  the .exe

freepdk, 2021-09-27:
@Skywalkerf34 :
VDD = 5.00V / VPP = 5.00V are the values easypdkprogtest sends.

Your values are 100% good. This verified that >98% of the PCB is working correct.

The remaining things on the PCB which might be wrong are just the resistors R18,R19,R20,R21,R22 (which is very very unlikely) or the soldering of the STM32 / the header is not good.
=> This should be easy to verify with a multimeter (check for shorts between the data lines on the header, check for continuity to resistors / resistance to the STM32).

After that said, it might just be that all your PCBs are working correct and you have a problem with the socket where you place the IC inside. Also make sure to place the IC (PFS154 / PFS173) at the bottom of the socket...

Skywalkerf34, 2021-09-27:
@freepdk
Thank you so much for your support
I have checked the MCU and resistor to header carefully and everything is right
But still same answer :-0
the "only" thing I didn't check are those adapter PCB design for PFS and PMS do you know if are they right about the design (schematic) ?

freepdk, 2021-09-27:
@Skywalkerf34
Which adapter PCBs are you refering to? The programmer is designed to use of the shelf sop16 adapter to be plugged in the programmer directly:  google search "sop16 adapter" => https://www.google.com/search?q=sop16+adapter

Skywalkerf34, 2021-09-27:
@freepdk
those here : https://github.com/free-pdk/easy-pdk-programmer-hardware/tree/master/adapter-pcbs
I think I put the finger on...those are for SOT6  :-5

Skywalkerf34, 2021-09-27:
Better read...10 times
I put the question seeing that PCB was exactly pinout form PADAUK DATASHEET and remembering designing those PCB crossing pin...

freepdk, 2021-09-27:
@Skywalkerf34
Unfortunately I don't have any experience with the adapter from here:  https://github.com/free-pdk/easy-pdk-programmer-hardware/tree/master/adapter-pcbs
For me it looks like you need the exact same socket as the creator of the adapter PCBs used. In case you just have a similar looking socket the pinout of the socket might be different.

I created a wire based adapter myself in the past... It took me also some tries to get the wiring right. So maybe something is wrong with your adapter.

Skywalkerf34, 2021-09-27:
@freepdk

My mistake!
I was stupidly thinking PADAUK did different pinout for the PFS and PMS series, so the adapter was necessary
As I solded my SOP 16 adapter to the universal I just make a "reverse" for bottom to plug on the programmer and...

TADA.... IT WORKS !!!!!!

The so call adapter are only necessary for the small SOP6 models but I didn't paid so much attention about  PADAUK datasheet PINOUT nor the "SOP6" indication on the adapter page....I shoud have read more carefully  again and again and again

freepdk, 2021-09-27:
@Skywalkerf34

> TADA.... IT WORKS !!!!!!

Great. Closing this issue now :-)

Skywalkerf34, 2021-09-27:
Now I got one working I can fix the few other programmer I have left
Maybe the next step would be for me to re-design a little the PCB with some change (diode really too small; OSCILLATOR could be SMD etc...
But you already do a GREAT JOB !!!!

freepdk, 2021-09-27:
There is already a re-designed PCB (called "lite") which reduced parts (no diodes at all).

The OSC and many other parts been chosen just by "lowest price" on LCSC almost 2 years ago... Back then the complete BOM was <US$2 :-)

Things changed a bit.

Closed 2021-09-27.

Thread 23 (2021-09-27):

vpp too low

Skywalkerf34, 2021-09-27:
@freepdk

I have one of this little series that give VDD 5.00 butVPP 0.65 volts ( screen and measured)
Any suggestion what to check ?

Kind regards

Skywalkerf34, 2021-09-27:
@freepdk
On the first one I double check all those resistors up to the MCU pin seem ok but not better,
so I change OP  with same bad result :-[

Skywalkerf34, 2021-09-27:
vref is 3.34

freepdk, 2021-09-27:
Since you have a working device you should be able to check some things quickly:
- start easypdkprogtest on the working device and measure + write down all voltages you see on the opamp pins
- start easypdkprogtest on the problematic device and do the same
=> This will show differences and might lead to the solution.

freepdk, 2021-09-28:
I added a picture with measurements from a good programmer:

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

Skywalkerf34, 2021-09-29:
@freepdk

Again, thanks a lot for your help
I order some new inductor that seem very similar to the reference you give in the BOM as the original manufacturer seem not popular here in my place.
It is supposed to be sent today by express and expected at home in about 4 days
As I receive I will swap the inductor and have to check about all voltages you kindly print for me.
I Will give you news then

freepdk, 2021-09-29:
More suggestions:
- check if L3 soldering is creating a short on PCB
- check orientation of U6 (MT3608), maybe it's rotated 180deg (pin1 of MT3608 is closest to the coil)
- remove L3 and measure voltage on C1 / C4 => should have 0V without L3

Skywalkerf34, 2021-10-04:
@freepdk

thanks a lot again for your kind support
I receive the new inductor and replace on the 2 "working" PCB
the results are exactly the same, with under voltage between C4 and D1
What the rule of Q1 that is driven by STM32 ? it should "drive the power in for the MT3608  right ?
Then what config I should run to check the voltage at that measuring point? for the moment I just plug the programmer to measure
If I remove R24 I notice that now voltage become almost 15v ( 14.4v exactly)

freepdk, 2021-10-04:
@Skywalkerf34

You should run the easypdkprog test  which outputs 5V on VDD and VPP.
The transistor (and the 15V output) should be enabled as soon as you connect the programmer to to USB .

>If I remove R24 I notice that now voltage become almost 15v ( 14.4v exactly) on one of the board
This is an interesting find. This suggests that (maybe after the opamp) something is pulling the output down (e.g. a small short - maybe solder bridge or pcb manufacturing problem, a shorted capacitor, ...).
You can try this theory by removing C2,C10,R15,R17.
easypdkprog might be unresponsive (since firmware might hang during startup if ADC measurement is missing) but you still should be able to make a measurement.

Skywalkerf34, 2021-10-04:
@freepdk

Hi,
Hope you are going well,
I try to remove those one by one with no change
removing/putting back R24 confirm this problem on the second board too

Easypdktest was giving quite good value. the problem seems to be on 15v line

This is really strange and at that step of understanding your schematics, I don't understand where can come from...

Skywalkerf34, 2021-10-04:
Should I try to remove  R14 and R20 pull down resistor ?

Skywalkerf34, 2021-10-04:
@freepdk

Removing R14 and R16 didn't change  :-(

Skywalkerf34, 2021-10-04:
@freepdk

I check the BOM and my boards and I notice that I use AS358MTR  your BOM said AS358**A**MTR
datasheet just said "_The AS358A has more stringent input offset voltage than the
AS358"_ I am not sure what that mean as there is no other explanation about!

What do you think?
I think there is a mistake somewhere as all the boards are reaction same way, but without deep understanding the schematic it is not so easy to found out what's wrong

freepdk, 2021-10-04:
@Skywalkerf34

* AS358 and AS358A should make no difference
* When you remove R24 you completely remove the opamp AND ALL FLLOWING components from the DCDC output. So it might be that the opamp just works fine but something else after the opamp pulls down the signal. For instance in case you would solder a resistor instead of a capacitor for C2 or C10 ... or there is a solder bridge at C2 or C10 or .... the output of the opamp would be pulled down which can pull down the complete voltage of the DCDC...
* removing R14/R20 will not help at all. This are part of voltage divider for the ADC (voltage measurement) in STM32. In case you remove them then STM32 will receive to high voltage on ADC pins and this might destroy the STM32.
* => Please remove the components I suggested: C2,C10,R15,R17.

Skywalkerf34, 2021-10-04:
@freepdk
_=> Please remove the components I suggested: C2,C10,R15,R17._

Already try without any better result :-(

freepdk, 2021-10-04:
Can you take a high resolution picture of your PCB (from the most bad PCB you have) and attach it here?

Skywalkerf34, 2021-10-04:
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

freepdk, 2021-10-04:
@Skywalkerf34

* **C4 seems much to small** (the bigger 1206 component was chosen for a reason). What cap did you use there (link to datasheet).
* soldering and orientation of ICs is looking ok
* picture 2 and 3 looks like some components (caps near the STM32 / resistors bottom left) might have solder bridges or are shifted to much and might create a short. You should add some flux and then hot air will pull them to correct positions and move the solder to to correct spots.

Skywalkerf34, 2021-10-04:
@freepdk
Capacitors near STM32 checked,
I cannot find the information about the C4 I used that time so I try to change for one I currently use on my design 10µF tantalum.....no change :-[

Skywalkerf34, 2021-10-04:
shit, I just discover that it was not 4.7µf but 47µf for C4.....

Skywalkerf34, 2021-10-04:
I am using schematic not the BOM list every time, maybe I should change to stronger glasses ;-)

Skywalkerf34, 2021-10-04:
@freepdk
So, I changed again C4 with 47µF polarized(chemical) capacitor result eep very similar with only 9.2 volts between D1 and C4

freepdk, 2021-10-04:
@Skywalkerf34

Do you have an oscilloscope ?

Skywalkerf34, 2021-10-04:
@freepdk
Yes for sure

freepdk, 2021-10-04:
I will do some test measurements later which might be helpful to get a clue what's going on with your boards.

To be honest, when I created and assembled the first programmer it immediately worked. I only had a solder bridge at the STM32 which shorted the two output pins connected to the programming header.
Since all your boards are affected something really strange is going on. Curious to find out :-)

Skywalkerf34, 2021-10-04:
@freepdk

This append to me time to time doing  new prototype design....It works immediately and confirm the design... but going to pre-serie then problem occurs ;-)

I do electronics dev for many years but now mainly from 80x51 to microchip then ATMEL but now almost everything with ESP32.
I have my own company and small assembly line for SMT.
Now I was looking for cheap MCU for very light (or cheap) project.

I really appreciate your kind help to solve the problem

freepdk, 2021-10-10:
@Skywalkerf34

The labeling suggest that this is a "LM358" from Texas Instruments.
However all genuine Texas Instruments LM358 ICs I have seen always have a good visible dot for pin 1. Also the Texas Instruments logo looks a bit strange as well.
In case this is a relabeled (cheap) opamp, chances are high that it will not work well / will not work at all with voltages >5V.

Skywalkerf34, 2021-10-11:
@freepdk

Thanks again for your support
I am convience there is global problem somewhere, and we are pointing the OP level part for several time.
I was out those days, Will will try to measure the output of the step-up but what was about clear is that without R24 wich power the OP the voltage was correct.
On same way I put back the resistor and remove OP and get same result (right voltage)

I will put order for some fresh new OP to an other shop and see what append then

Will keep you informed as I get some result

Skywalkerf34, 2021-10-30:
@freepdk

Hi,

I receive the new OP and change on one of the most "working" board but no change :-[
So I come back to one I put on the side that was given already a bad vpp value and discover that that board give good 15 volts and except vvp other voltage you kindly indicate was about ok. So I check that last one an just press a little more pin18 of STM32...tada vpp come good then :-)
So I set a pfs154 on the adapter and probe => work !
erase => work !
program helloword => work !
 start => hello world!

So, by the end, This is just my original wiring of the board that work good now with the LM358 and that "small capacitor  on C4 and some inductor I bought at the beginning.

Now, thanks to your help, I have at least ONE programmer that works and I can now investigate why the other didn't run well up to now.

Thanks again for all your patience and great help to guide me on the way to fix

Skywalkerf34, 2021-11-05:
@freepdk
I am still facing problem on the 4 other Programmer can you be kind to explain the purpose of Q2 and Q1 and confirm D2 and D3 are connected to Q2 ( didn't find information on the schematic)

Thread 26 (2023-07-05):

Fresh boards, can't flash via DFU

cnlohr, 2023-07-05:
I ordered several boards of this variant from JLCPCB.  And, they used a STM32F072C8T6 (C80488) but it seems the parts don't come from the factory with a USB bootloader for DFU. According to the datasheet, for DFU USB should be on PB6/7 instead of PA11/12.

What is the actual procedure for getting an appropriate bootloader onto the STM32F072C8T6, or mechanism to use other programmer?

I have an ST-Link programmer, which is OpenOCD compatible, but I don't see any indication how to use the SWD programming with this part.  What is the recommended path forward?

cnlohr, 2023-07-05:
Using st-flash succeeds but the part remains dysfunctional :(

```
st-flash write EASYPDKPROG.bin 0x08000000
st-flash 1.6.0
2023-07-05T16:11:19 INFO usb.c: -- exit_dfu_mode
2023-07-05T16:11:19 INFO common.c: Loading device parameters....
2023-07-05T16:11:19 INFO common.c: Device connected is: F07x device, id 0x20016448
2023-07-05T16:11:19 INFO common.c: SRAM size: 0x4000 bytes (16 KiB), Flash: 0x10000 bytes (64 KiB) in pages of 2048 bytes
2023-07-05T16:11:19 INFO common.c: Attempting to write 35108 (0x8924) bytes to stm32 address: 134217728 (0x8000000)
Flash page at addr: 0x08008800 erased
2023-07-05T16:11:19 INFO common.c: Finished erasing 18 pages of 2048 (0x800) bytes
2023-07-05T16:11:19 INFO common.c: Starting Flash write for VL/F0/F3/F1_XL core id
2023-07-05T16:11:19 INFO flash_loader.c: Successfully loaded flash loader in sram
 18/18 pages written
2023-07-05T16:11:21 INFO common.c: Starting verification of write complete
2023-07-05T16:11:21 INFO common.c: Flash written and verified! jolly good!
```

cnlohr, 2023-07-05:
All boards have the same issue, all flash fine, all report low speed device.  Are there any extra fuses or anything that need to be set beforehand?

cnlohr, 2023-07-05:
I am using the variant from thomasesr. https://github.com/thomasesr/easy-pdk-programmer-hardware which has flipped D+/D- it seems.  I wish I could open an issue to warn others.

But even when flipping them, the part does not appear to come online.

cnlohr, 2023-07-05:
Aah! That was it.  Just flipped D+/D- on Thomasesr's version.

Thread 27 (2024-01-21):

PCB bill of materials: LCSC part number C177602 no longer exists

basilhussain, 2024-01-21:
In the included bill of materials, the listed LCSC part number for the 240k resistors, C177602, no longer exists at LCSC. As in, not "out of stock", but just completely doesn't exist - you will find no results returned when searching for that part number.

This means that when using the 'BOM Tool' at the LCSC website to import the list of parts, the 240k resistors will be missed out.

I suggest a replacement part number: [C144679](https://www.lcsc.com/product-detail/Chip-Resistor-Surface-Mount_YAGEO-AC0603FR-07240KL_C144679.html).

cpldcpu, 2024-01-21:
Thank you for this input! Can you submit a pull request?

Closed 2024-01-23.

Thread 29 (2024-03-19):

Pcb ,  schematic file

Misk1234, 2024-03-19:
Where is the board pcb file and schematic file ( not image or pdf)

spth, 2024-03-19:
https://github.com/free-pdk/easy-pdk-programmer-hardware/tree/master/easyeda

Closed 2024-03-19.

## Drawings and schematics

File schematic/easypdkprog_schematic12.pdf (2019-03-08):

+15V

+5V

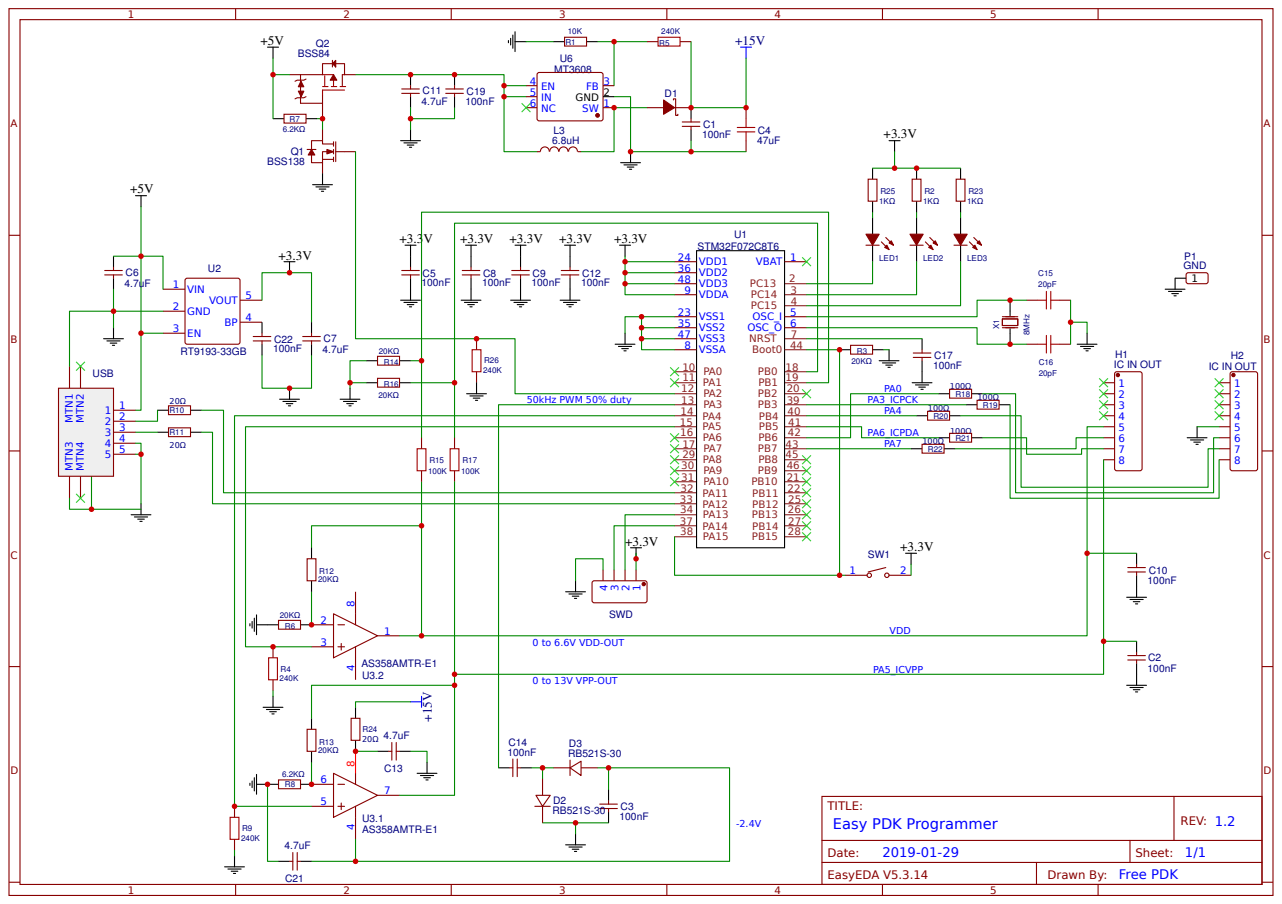
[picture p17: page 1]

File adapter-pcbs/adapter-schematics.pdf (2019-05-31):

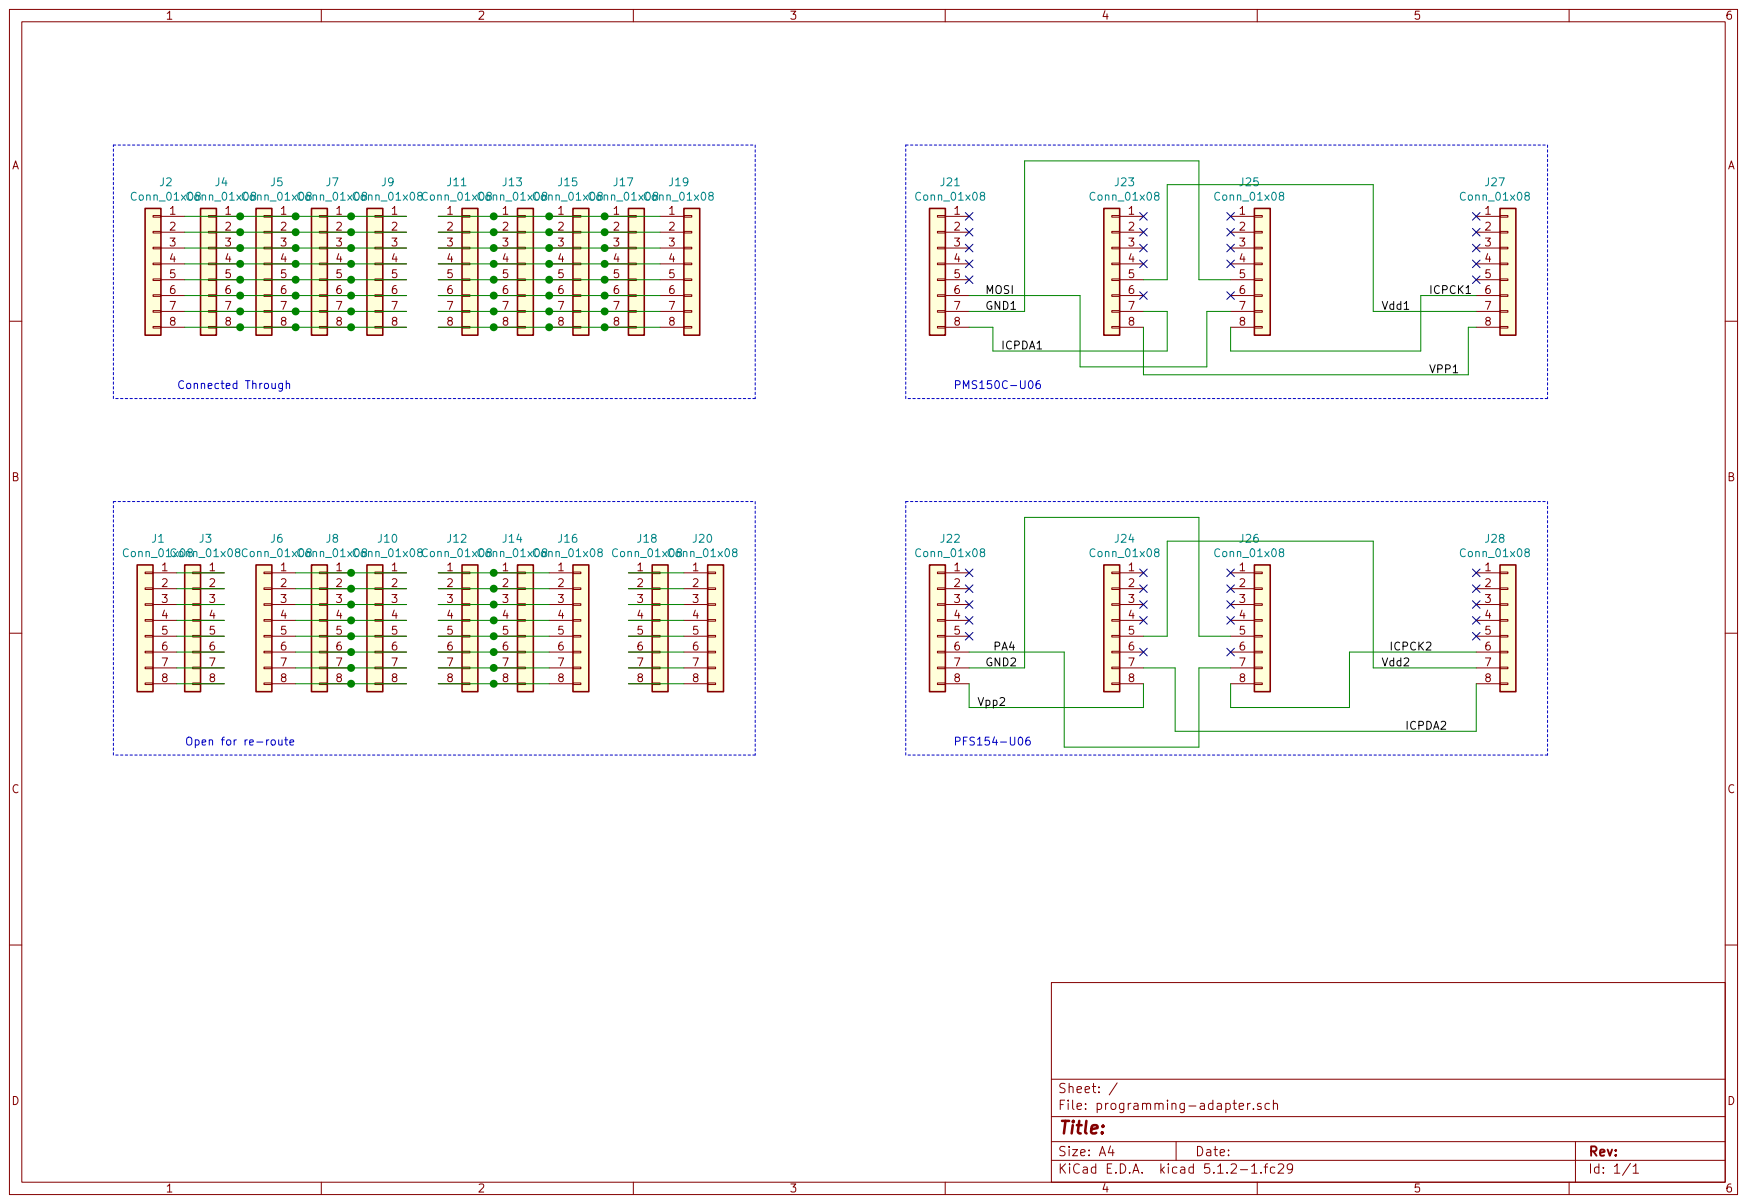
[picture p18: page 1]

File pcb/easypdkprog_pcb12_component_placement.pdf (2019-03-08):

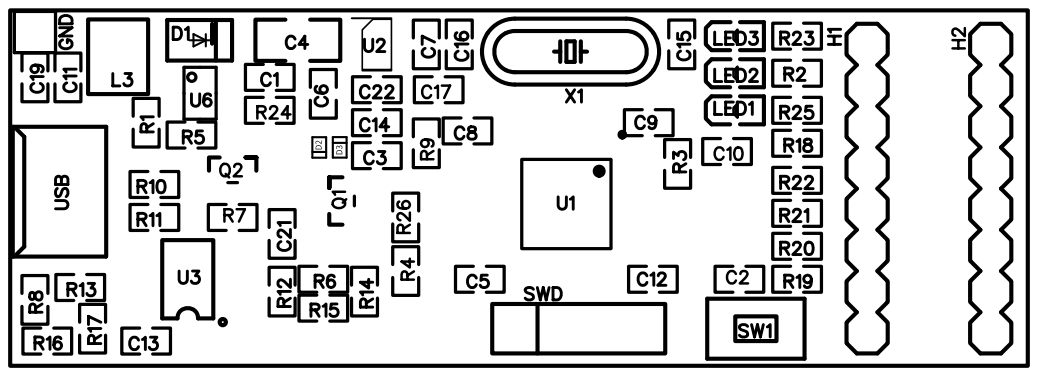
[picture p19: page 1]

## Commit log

2019-03-23 fix wrong part in bom (correct is 2x 8 pin female header)
    [easypdkprog_pcb12_bom.csv]
2019-05-31 Adapter pcbs (#2)
    add adapter pcbs for SOT23-6
    [programming-adapter.kicad_pcb, programming-adapter.sch]
2019-08-31 add single (non panelized) gerber
2019-08-31 changed panel layout to have rails on sides, so it matches JLCPCB new min 7x7cm rules for panel
2019-09-05 add bom file which can be imported at LCSC.com
2019-10-28 Extension bom fix
    * Fixed csv commas for github visualization
    * Fixed LCSC bom extension typo
    [easypdkprog_pcb12_bom.csv, easypdkprog_pcb12_bom_LCSC_format.xlsx]
2020-02-04 Add files for kitspace.org (kitspace.yaml, unpack gerber) (#12)
    [Gerber_BoardOutline.GKO, Gerber_BottomLayer.GBL, Gerber_BottomSolderMaskLayer.GBS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]
2021-09-28 add PCB picture with voltages for troubleshooting (needs to run easypdkprog test)
2022-01-13 add interactive component placement bom (https://github.com/openscopeproject/InteractiveHtmlBom)
2022-01-13 make link to interactive component placement bom clickable from github
2022-01-13 fix link for interactive component placement bom
2024-01-21 Update PCB BOM
    LCSC part number C177602 (240k resistor) no longer available, substitute with another part.
    [easypdkprog_pcb12_bom.csv, easypdkprog_pcb12_bom_LCSC_format.xlsx]
